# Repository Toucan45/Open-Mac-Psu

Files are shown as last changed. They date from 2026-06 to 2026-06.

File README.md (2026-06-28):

# Open Mac Psu

_an open solution to replacing faulty power supplies in macintosh se and se/30s_

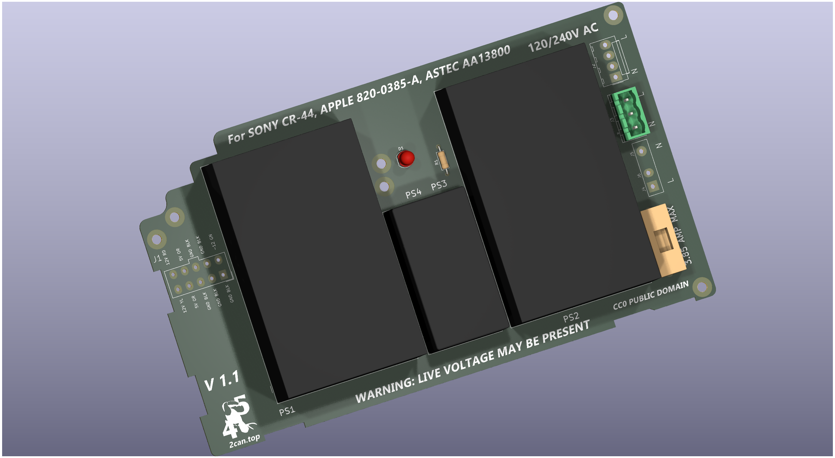
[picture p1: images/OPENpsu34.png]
A render of the Open Mac Psu with components added


## Gerbers
Gerbers can be found [here](https://github.com/Toucan45/Open-Mac-Psu/tree/573422227fe0c304fcaa28862943a276e656f22d/Gerbers) or in the /gerbers directory. You may also edit and generate gerbers however you may please with the KiCad files. <br>
I personally found that JLCPCB provided the cheapest prices as of 2026, but I encourage you to check multiple places. 

## BOM

Here you can find a BOM for the different power supply variations : <br>
[Mouser BOM/Cart link](https://www.mouser.com/Tools/SavedCart/Share?AccessID=ede8b16457) <br>
[Mouser BOM for power cord](https://www.mouser.com/Tools/SavedCart/Share?AccessID=fe829de712) <br>
[Apple PSU bom xlsx file](https://github.com/Toucan45/Open-Mac-Psu/blob/32ab051dbc95035807b1feb3e86211b6a79a08f5/BOM/AppleBom.xlsx) <br>
[Astec PSU bom xlsx file](https://github.com/Toucan45/Open-Mac-Psu/blob/32ab051dbc95035807b1feb3e86211b6a79a08f5/BOM/AstecBom.xlsx) <br>
[SONY PSU bom xlsx file](https://github.com/Toucan45/Open-Mac-Psu/blob/32ab051dbc95035807b1feb3e86211b6a79a08f5/BOM/SonyBom.xlsx) <br>
[Power Cord bom xlsx file](https://github.com/Toucan45/Open-Mac-Psu/blob/32ab051dbc95035807b1feb3e86211b6a79a08f5/BOM/J1Cord.xlsx) </p>

The IRM power supplies seem to be sparratically in stock on mouser and digikey. If they are out of stock on your favorite part supplier, consider shopping around. The xlsx BOM files can be imported to any of your favorite part supplier(s).

# Right to resale or reproduction
Any consumer, industry, or company has the right to edit, modify, reproduce, and resell any files assosciated with this project, including schematics, pictures, BOMs, and finalized PCBs. <br>
"The person who associated a work with this deed has dedicated the work to the public domain by waiving all of his or her rights to the work worldwide under copyright law, including all related and neighboring rights, to the extent allowed by law.
You can copy, modify, distribute and perform the work, even for commercial purposes, all without asking permission." <br>
"The person who associated a work with this deed makes no warranties about the work, and disclaims liability for all uses of the work, to the fullest extent permitted by applicable law." </p>

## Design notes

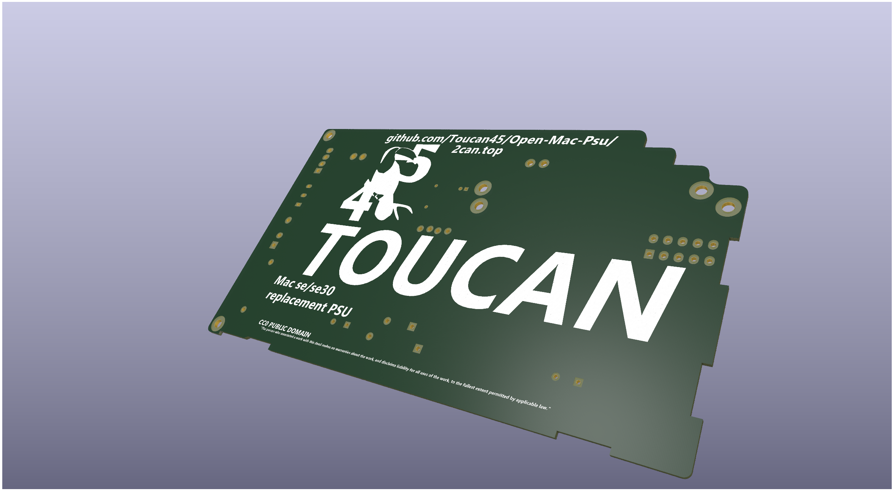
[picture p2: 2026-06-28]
images/OPENpsu33.png

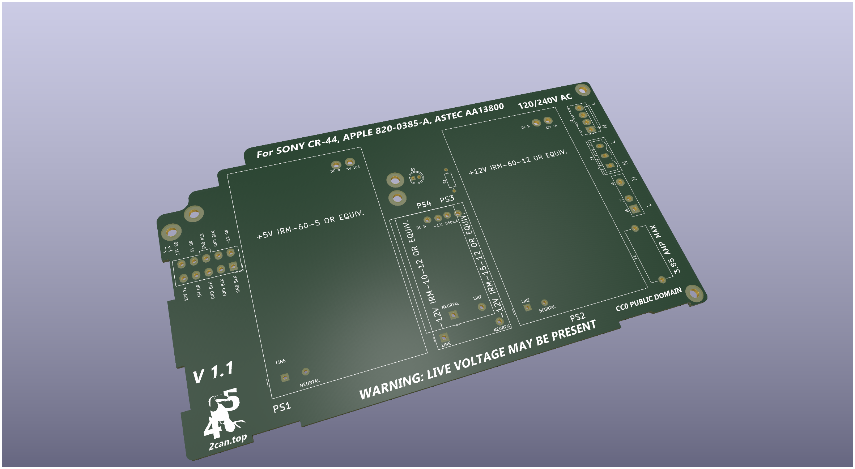
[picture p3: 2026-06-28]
images/OPENpsu32.png

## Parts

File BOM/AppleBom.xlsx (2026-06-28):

Mfr Part Number (Input) | Description (Input) | Mfr Part Number | Mouser Part Number | Manufacturer Name | Description | Unit Price 1 (USD) | Price 2 (USD) | Price 3 (USD) | Order Quantity | Order Unit Price (USD) | Price 4 (USD) | Price 5 (USD) | Min./Mult. | Availability | Lead Time in Days | Lead Time in Weeks | Lifecycle | NCNR | RoHS | Pb Free | Package Type | Package Quantity | Datasheet URL | Product Image | Design Risk | Packaging Choice | Estimated Tariff Price | Estimated Tariff Ext.
IRM-10-12 | PSU4 | IRM-10-12 | 709-IRM10-12 | MEAN WELL | Power Supplies - Board Mount Power Supplies - Board Mount 12V 0.85A 10.2W 85-264Vin Encap PS |  |  |  | 1 | $7.20 |  |  | 1/1 |  | 125 | 18 |  |  | Yes | No |  | 270 | https://www.meanwellusa.com/webapp/product/search.aspx?prod=IRM-10 |  | Product has high popularity and is readily available. |  | $2.74 | $2.74
IRM-60-12 | PSU2 | IRM-60-12 | 709-IRM60-12 | MEAN WELL | Power Supplies - Board Mount Power Supplies - Board Mount AC-DC PCB-Mount Green Power Module |  |  |  | 1 | $15.00 |  |  | 1/1 | 642 | 130 | 19 |  |  | Yes | No |  | 60 | https://www.meanwellusa.com/webapp/product/search.aspx?prod=IRM-60 |  | Product has high popularity and is readily available. |  | $5.70 | $5.70
26604040 | J2 (APPL) | 26-60-4040 | 538-26-60-4040 | Molex | Headers & Wire Housings Headers & Wire Housings VERT PCB HDR 4P TIN FRICTION LOCK |  |  |  | 1 | $0.42 |  |  | 1/1 | 53,602 | 133 | 19 |  |  | Yes | No | BULK | 10,350 | https://www.molex.com/en-us/products/part-detail/26604040?display=pdf |  | Product has high popularity and is readily available. |  | $0.034 | $0.03
34.3123 | FUSE | 0034.3123 | 693-0034.3123 | Schurter | Cartridge Fuses Cartridge Fuses 5X20 250V 4A |  |  |  | 1 | $0.64 |  |  | 1/1 | 337 | 138 | 20 |  |  | Yes | Yes | BULK | 1,000 | https://www.mouser.com/datasheet/3/386/1/typ_FST_5x20.pdf |  | Product has high popularity and is readily available. |  | $0.058 | $0.06
39281103 | J1 | 39-28-1103 | 538-39-28-1103 | Molex | Headers & Wire Housings Headers & Wire Housings 10 CKT VERT HEADER |  |  |  | 1 | $1.54 |  |  | 1/1 | 16,910 | 77 | 11 |  |  | Yes | Yes | BULK | 250 | https://www.molex.com/en-us/products/part-detail/39281103?display=pdf |  | Product has high popularity and is readily available. |  | $0.123 | $0.12
IRM-60-5 | PSU1 | IRM-60-5 | 709-IRM60-5 | MEAN WELL | Power Supplies - Board Mount Power Supplies - Board Mount AC-DC PCB-Mount Green Power Module |  |  |  | 1 | $15.00 |  |  | 1/1 |  | 131 | 19 |  |  | Yes | No |  | 60 | https://www.meanwellusa.com/webapp/product/search.aspx?prod=IRM-60 |  | Product has high popularity and is readily available. |  | $5.70 | $5.70
C566E-RFE-CV0X0BB2 | D1 | C566E-RFE-CV0X0BB2 | 941-C566ERFECV0X0BB2 | Cree LED | Single Color LEDs Single Color LEDs |  |  |  | 1 | $0.17 |  |  | 1/1 | 3,731 | 36 | 6 | New Product |  | Yes | Yes | AMMO PACK | 3,000 | https://downloads.cree-led.com/files/ds/h/HB-C556E.pdf |  | Product is new and is readily available.
SFR25H0002200FR500 | R1 | SFR25H0002200FR500 | 594-SFR25H0002200FR5 | Vishay | Metal Film Resistors - Through Hole Metal Film Resistors - Through Hole SFR25H 1% R5 220R |  |  |  | 1 | $0.25 |  |  | 1/1 | 1,834 | 84 | 12 | New at Mouser |  | Yes | Yes |  | 5,000 | https://www.vishay.com/doc?28722 |  | Product is new and is readily available. |  | $0.025 | $0.03
696108003002 |  | 696108003002 | 710-696108003002 | Wurth Elektronik | Fuse Holder Fuse Holder WR-FSH BLOCKS PCB CLIP COVER THT | $0.67 |  |  | 1 | $0.67 |  |  | 1/1 | 13,781 | 119 | 17 |  | No | Yes | Yes | BULK | 200 | https://www.we-online.com/components/products/datasheet/696108003002.pdf |  | Product has high popularity and is readily available.
696122003001 |  | 696122003001 | 710-696122003001 | Wurth Elektronik | Fuse Holder Accessories Fuse Holder Accessories WR-FSH PCB CLIP COVER THT WRFSH | $0.25 |  |  | 1 | $0.25 |  |  | 1/1 | 26,193 | 91 | 13 |  | No | Yes | Yes | BULK | 200 | https://www.we-online.com/components/products/datasheet/696122003001.pdf |  | Product has high popularity and is readily available.

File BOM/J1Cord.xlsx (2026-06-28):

Mfr Part Number (Input) | Quantity 1 | Mfr Part Number | Mouser Part Number | Manufacturer Name | Description | Unit Price 1 (USD) | Price 2 (USD) | Price 3 (USD) | Order Quantity | Order Unit Price (USD) | Price 4 (USD) | Price 5 (USD) | Min./Mult. | Availability | Lead Time in Days | Lead Time in Weeks | Lifecycle | NCNR | RoHS | Pb Free | Package Type | Package Quantity | Datasheet URL | Product Image | Design Risk | Packaging Choice
WM3704-ND | 1 | 39-01-2100 | 538-39-01-2100 | Molex | Headers & Wire Housings Headers & Wire Housings 10 CKT RCPT HOUSING | $0.44 |  |  | 2 | $0.44 |  |  | 1/1 | 84,229 | 119 | 17 |  | No | Yes | No | BULK | 2,500 | https://www.molex.com/en-us/products/part-detail/39012100?display=pdf |  | Product has high popularity and is readily available.
215340-1124 | 10 | 215340-1124 | 538-215340-1124 | Molex | Jumper Wires Jumper Wires MINI-FIT JR. F-F 300MM 16 AWG BK Sn | $0.899 |  |  | 10 | $0.899 |  |  | 1/1 | 758 | 161 | 23 |  | No | Yes | No | BULK | 1,000 | https://www.molex.com/en-us/products/part-detail/2153401124?display=pdf |  | Product has moderate popularity and is readily available.

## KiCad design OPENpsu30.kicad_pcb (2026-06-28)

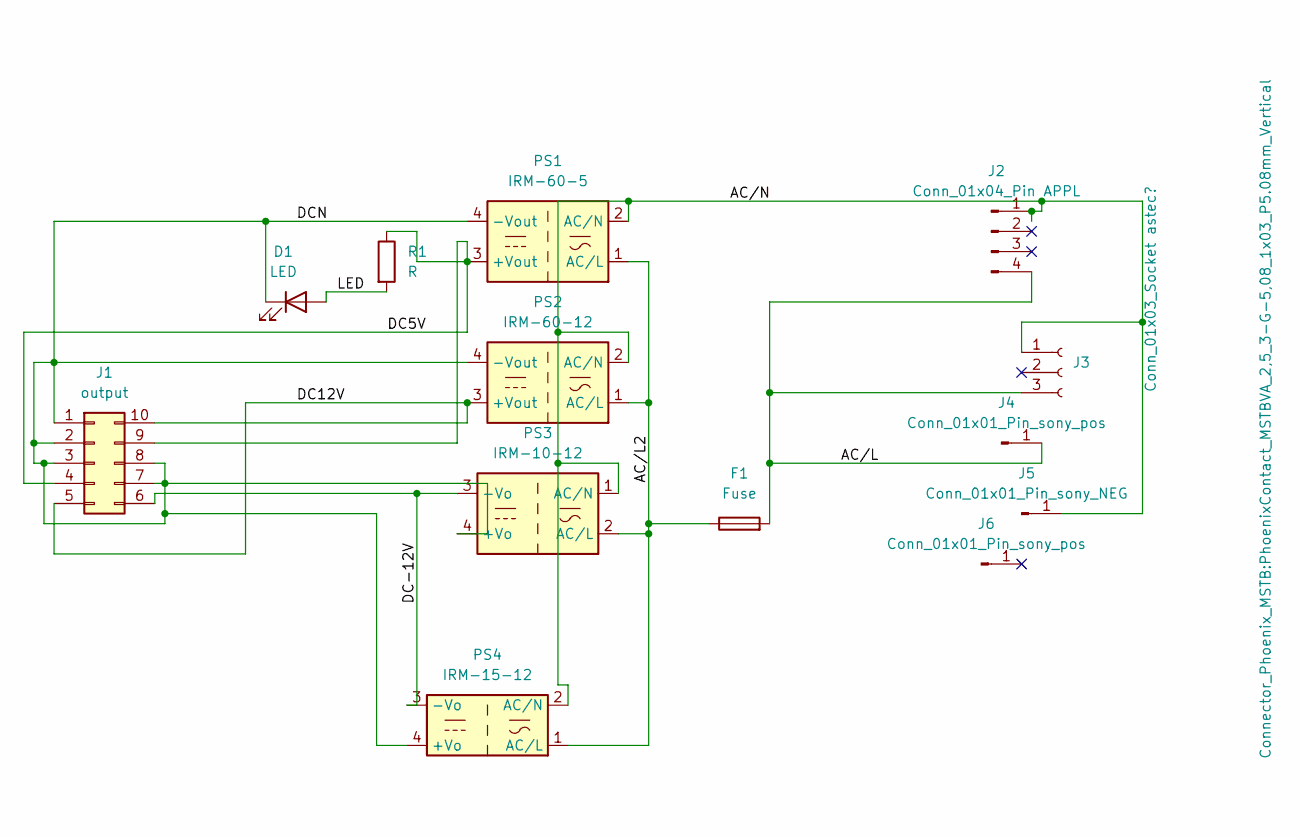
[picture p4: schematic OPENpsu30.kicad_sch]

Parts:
D1: LED; LED_D5.0mm
F1: Fuse; Fuseholder_Cylinder-5x20mm_Stelvio-Kontek_PTF78_Horizontal_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
J1: output; Molex_Mini-Fit_Jr_5566-10A_2x05_P4.20mm_Vertical
J2: Conn_01x04_Pin APPL; Molex_KK-396_A-41791-0004_1x04_P3.96mm_Vertical
J3: Conn_01x03_Socket astec?; PhoenixContact_MSTBVA_2,5_3-G-5,08_1x03_P5.08mm_Vertical
J4, J6: Conn_01x01_Pin_sony_pos; pin 1.65
J5: Conn_01x01_Pin_sony_NEG; pin 1.65
PS1: IRM-60-5; Converter_ACDC_MeanWell_IRM-60-xx_THT
PS2: IRM-60-12; Converter_ACDC_MeanWell_IRM-60-xx_THT
PS3: IRM-10-12; Converter_ACDC_MeanWell_IRM-10-xx_THT
PS4: IRM-15-12; Converter_ACDC_MeanWell_IRM-20-xx_THT
R1: R; R_Axial_DIN0207_L6.3mm_D2.5mm_P10.16mm_Horizontal

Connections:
/<NO NET>: F1.1, PS1.1 (AC/L), PS2.1 (AC/L), PS3.2 (AC/L), PS4.1 (AC/L)
/AC/L: F1.2, J2.4, J3.3, J4.1
/AC/N: J2.1, J3.1, J5.1, PS1.2 (AC/N), PS2.2 (AC/N), PS3.1 (AC/N), PS4.2 (AC/N)
/DC5V: J1.4, J1.9, PS1.3 (+Vout), R1.1
/DC12V: J1.5, J1.10, PS2.3 (+Vout)
/DC-12V: J1.6, PS3.3 (-Vo), PS4.3 (-Vo)
/DCN: D1.1 (K), J1.1, J1.2, J1.3, J1.7, J1.8, PS1.4 (-Vout), PS2.4 (-Vout), PS3.4 (+Vo), PS4.4 (+Vo)
/LED: D1.2 (A), R1.2

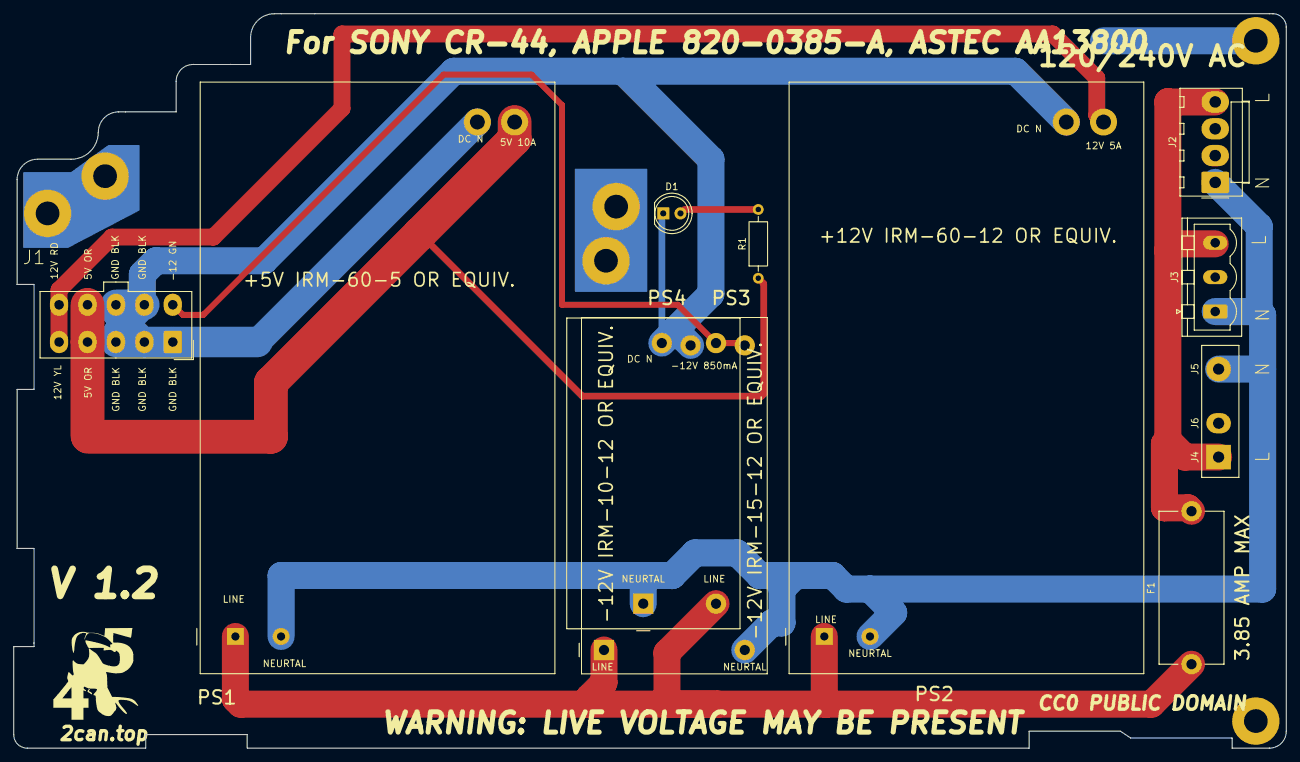
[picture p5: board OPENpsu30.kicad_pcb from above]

Board: 2 copper layers, 188.0 x 108.5 mm, 14 parts (1 on the bottom side), 8 nets.

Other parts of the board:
f: LOGO

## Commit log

2025-10-10 upd ver
    [OPENpsu30.kicad_pcb]
2025-10-10 upd + add images
    [OPENpsu30.kicad_pcb]
2025-10-11 upd ver #
    [OPENpsu30.kicad_pcb]
2026-06-28 Add Mouser BOM link to README
2026-06-28 add BOMs
    [AppleBom.xlsx, AstecBom.xlsx, GeneralBomF.xlsx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]
2026-06-28 Update README with more BOM links
    Added additional BOM links for various power supply variations.
2026-06-28 Fix HTML entities in BOM section of README
2026-06-28 Add placeholder file in Gerbers directory
2026-06-28 add gerbers
    [OPENpsu30-B_Cu.gbr, OPENpsu30-B_Mask.gbr, OPENpsu30-B_Paste.gbr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]
2026-06-28 Fix Gerber links and add resale rights information
    Updated Gerber file links and reinstated resale rights section.

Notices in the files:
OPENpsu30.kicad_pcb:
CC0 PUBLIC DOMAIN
